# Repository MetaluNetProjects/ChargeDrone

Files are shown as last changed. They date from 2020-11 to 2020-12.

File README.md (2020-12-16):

# ChargeDrone
Charger for 2-li_Ion-18650-batteries pack.

## exported files:

CHARGEDRONE-v1.zip : PCB manufacturer files

ChargeDronePCB-v1.xls : Bill of Materials

ChargeDrone-schema.pdf : schematic

ChargeDroneWRL-v1.zip : 3D export

PlexiCutting/ : directory containing plexiglas cutting files

### metalu.net 2020 for GroupeF

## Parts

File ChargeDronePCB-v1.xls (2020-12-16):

Id | Designator | Package | Quantity | Designation | Supplier and ref
1 | J2 | PackBatt | 1 | Pack2Batts | 4 X https://fr.farnell.com/keystone/54/battery-clip-18mm-cell-pcb-through/dp/1888422
3 | U1,U2 | TP4056 | 2 | TP4056 | https://www.gotronic.fr/art-module-chargeur-accus-li-ion-gt058-26089.htm
4 | J1,J4 | TerminalBlock_bornier-2_P5.08mm | 2 | Alim | 2 X https://fr.farnell.com/mean-well/lrs-50-5/alimentation-ac-dc-5v-10a/dp/2815996
5 | R1,R2,R3,R4 | R_Axial_DIN0207_L6.3mm_D2.5mm_P7.62mm_Horizontal | 4 | 1k | https://fr.farnell.com/multicomp/mf25-1k/resistance-1k-0-25w-1/dp/9341102
7 | D1,D3 | LED_D3.0mm | 2 | LEDG | https://fr.farnell.com/broadcom-limited/hlmp-1790/led-3mm-vert/dp/1003209
8 | D2,D4 | LED_D3.0mm | 2 | LEDR | https://fr.farnell.com/broadcom-limited/hlmp-1700/led-3mm-rouge/dp/1003207

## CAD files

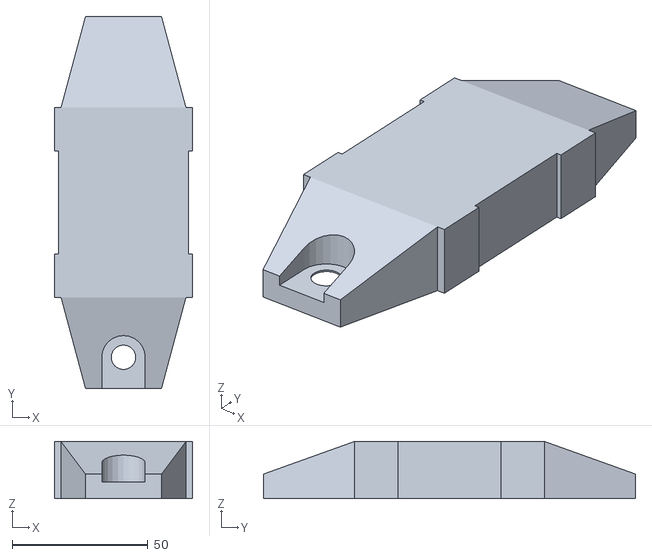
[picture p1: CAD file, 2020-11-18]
PackBattNano.obj
51.0 x 137.0 x 21.0

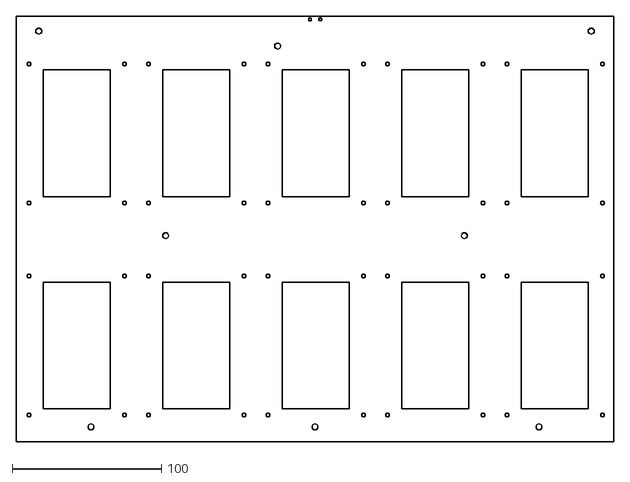
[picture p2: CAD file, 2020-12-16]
PlexiCutting/plexi.dxf
400.0 x 285.0

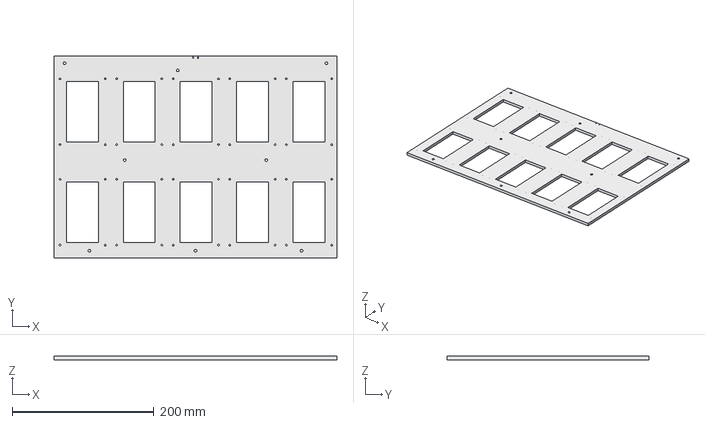
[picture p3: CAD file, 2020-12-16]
PlexiCutting/Decoupe plexi.FCStd
400.0 x 285.0 x 5.00 mm

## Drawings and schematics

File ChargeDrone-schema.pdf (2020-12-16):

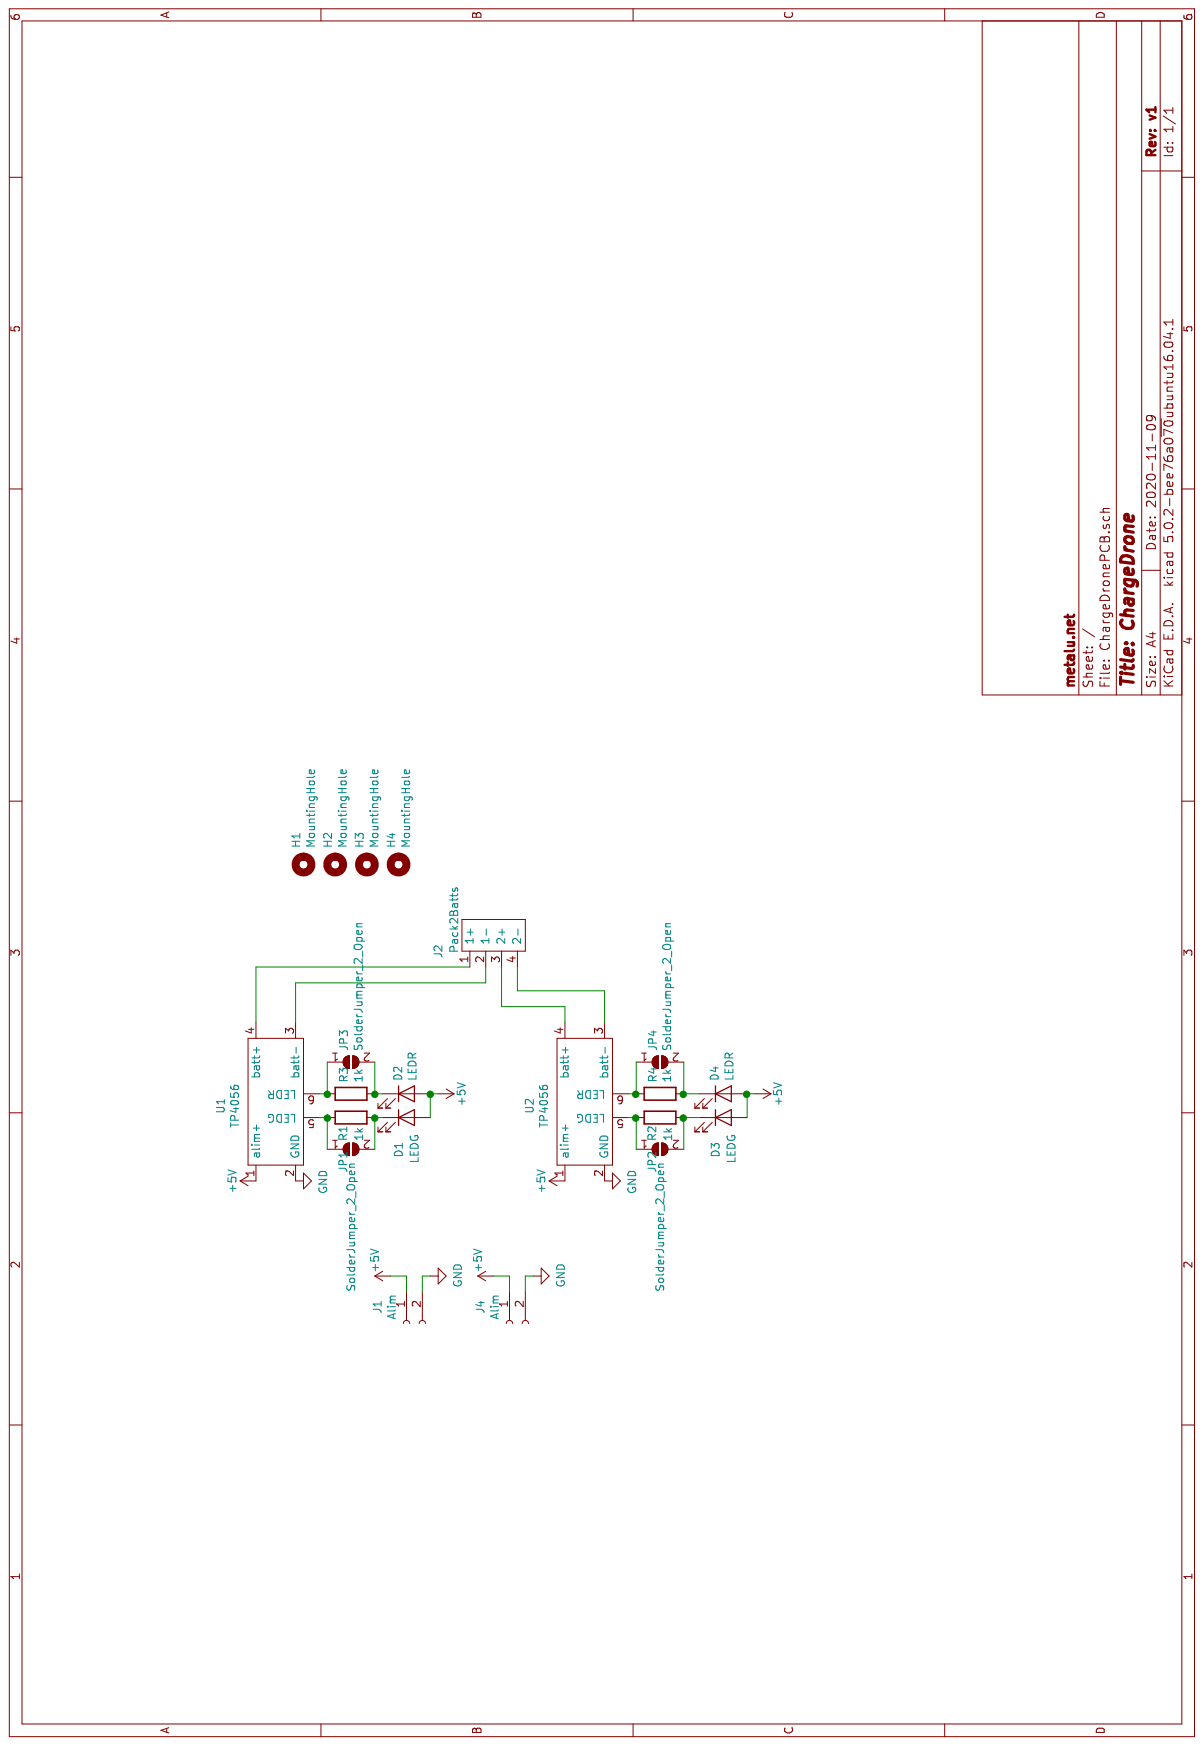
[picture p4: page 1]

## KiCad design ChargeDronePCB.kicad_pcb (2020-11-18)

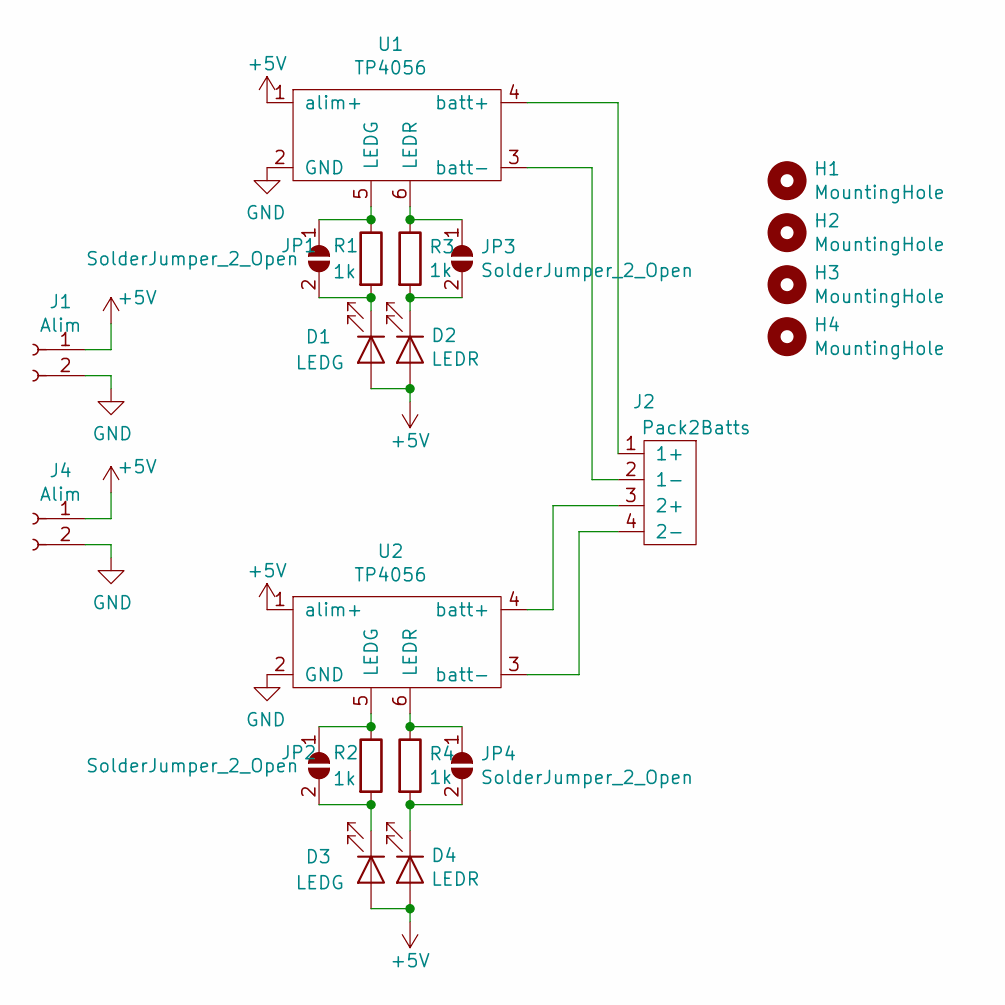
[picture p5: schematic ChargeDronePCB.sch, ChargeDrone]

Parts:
D1, D3: LEDG; LED_D3.0mm
D2, D4: LEDR; LED_D3.0mm
H1, H2, H3, H4: MountingHole; MountingHole_3.2mm_M3_DIN965_Pad
J1, J4: Alim; TerminalBlock_bornier-2_P5.08mm
J2: Pack2Batts; PackBatt
JP1, JP2, JP3, JP4: SolderJumper_2_Open; GS2
R1, R2, R3, R4: 1k; R_Axial_DIN0207_L6.3mm_D2.5mm_P7.62mm_Horizontal
U1, U2: TP4056

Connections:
+5V: D1.2 (A), D2.2 (A), D3.2 (A), D4.2 (A), J1.1, J4.1, U1.1 (alim+), U2.1 (alim+)
GND: J1.2, J4.2, U1.2 (GND), U2.2 (GND)
unnamed: D1.1 (K), JP1.2 (B), R1.2
unnamed: D2.1 (K), JP3.2 (B), R3.2
unnamed: D3.1 (K), JP2.2 (B), R2.2
unnamed: D4.1 (K), JP4.2 (B), R4.2
unnamed: J2.1 (1+), U1.4 (batt+)
unnamed: J2.2 (1-), U1.3 (batt-)
unnamed: J2.3 (2+), U2.4 (batt+)
unnamed: J2.4 (2-), U2.3 (batt-)
unnamed: JP1.1 (A), R1.1, U1.5 (LEDG)
unnamed: JP2.1 (A), R2.1, U2.5 (LEDG)
unnamed: JP3.1 (A), R3.1, U1.6 (LEDR)
unnamed: JP4.1 (A), R4.1, U2.6 (LEDR)

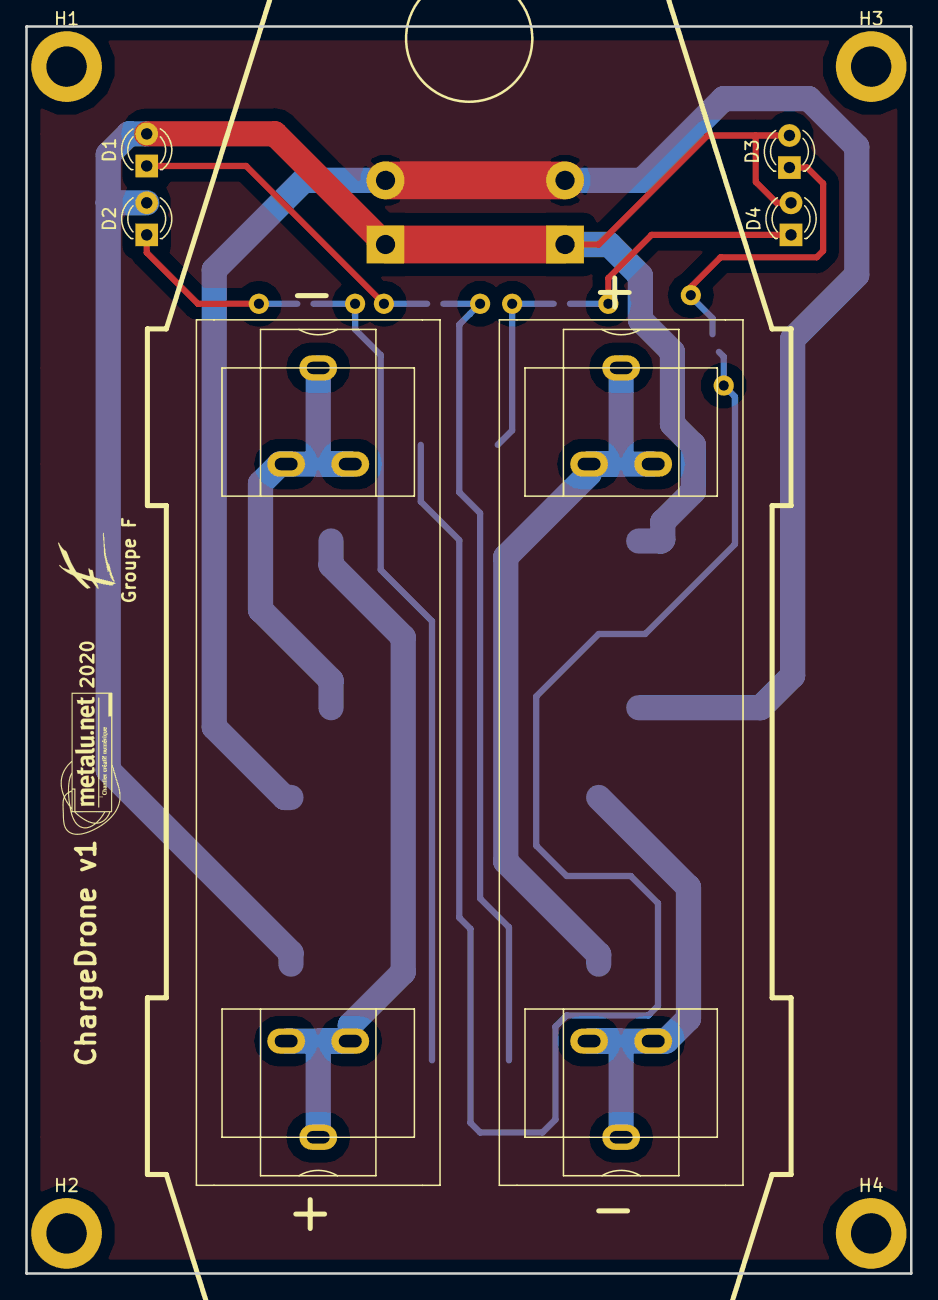
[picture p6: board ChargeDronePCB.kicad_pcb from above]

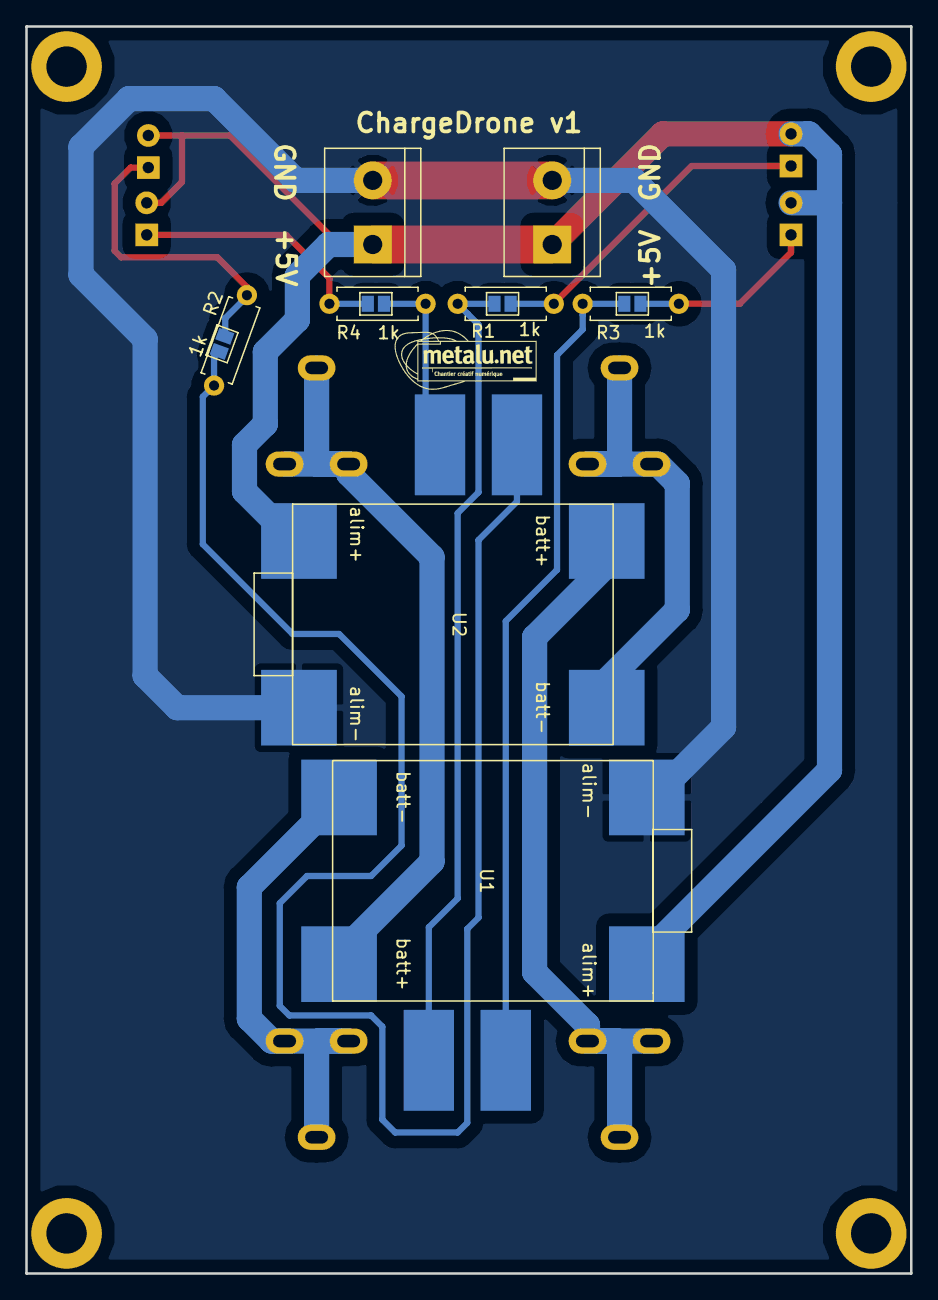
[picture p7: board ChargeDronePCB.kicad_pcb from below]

Board: 2 copper layers, 70.1 x 98.8 mm, 21 parts (12 on the bottom side), 14 nets.

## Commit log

2020-12-16 add ChargeDrone-schema.pdf
2020-12-16 add BOM as xls, and update README
    [ChargeDronePCB-v1.xls]
2020-12-16 add plexi cutting files
    [Decoupe plexi.FCStd, plexi.dxf]
